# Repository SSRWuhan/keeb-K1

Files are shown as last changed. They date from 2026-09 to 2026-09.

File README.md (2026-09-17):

# keeb-K1
This is my keyboard design for the KEEB program from Hack Club.

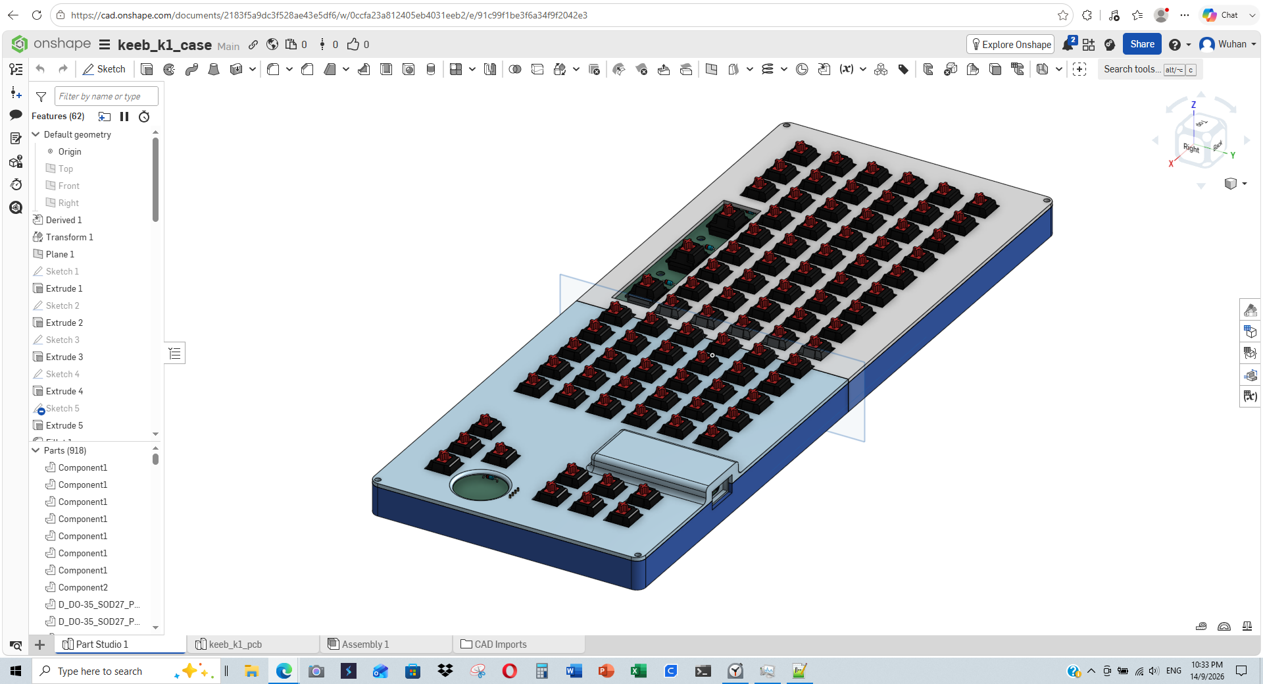
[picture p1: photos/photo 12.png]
Keyboard


This is my very first keyboard! I have designed it so that you can have 6 configurable keys for macros or any other thing, along with joystick for scrolling or for using it as a mouse.

This was my first time making a PCB and writting firmware. Even though I already have experience with CAD, I did learn a few new things while making this.

NOTE: This project is still in active development as I still haven't made it in real life. Also, The firmware is complete, but support for vial is still in the works. Thus, `vial.json` won't work.

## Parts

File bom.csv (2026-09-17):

Product | Description | Quantity | Price(Taka/BDT) | Price(USD) | Sale price(As of when writing this)(Taka/BDT) | Link | Shipping Fee(Taka) | Extra Notes
Rspberry pi pico | The microcontroller | 1 | 1119 | 9.06 | 959 | 【Clearance Markdowns】 Raspberry Pi Pico Board RP2040 TYPE-C / MICRO Dual-Core 264KB ARM Low- Microcomputers High-Performance Cortex-M0+ Processor | Daraz.com.bd | Free(as of writing this)
Mx Cherry linear switches | Switches for the Keyboard | 91 | 3736 | 30.25 | 1532 | 20-100pc Mechanical Keyboard Switches Blue Red Brown Switch Customizable Hot-Swappable 3 Pins Cross Stem for Mechanical Keyboard | Daraz.com.bd | 170 | Due to me needing 91 switches I had to buy the 100 set of switches.
Keycaps set | Base keycap set | 1 | 2366 | 19.16 | 968 | 104pcs ABS Universal Mechanical Keyboard Keycaps Ergonomic Blank Keycaps For Cherry MX Keyboard Replacement OEM Backlit Key Cap | Daraz.com.bd | 170 | This was the only good looking keycap set I could find.
1N4148 Diodes | The diodes for the keyboard matrix. | 91 | 892 | 7.22 | 379 | 100/350pcs Fast Switching Schottky Diode Assorted Kit 1N4001 1N4004 1N4007 1N5408 UF4007 FR207 1N5817 1N5819 1N5822 1N4148 RL207 | Daraz.com.bd | 170 | Due to me only finding a pack of 100 that was the most reliable, I had to buy 100.
Stabilizers | stabilizers for keys bigger than 1u. | 1 set | 979 | 7.93 | 839 | 【Premium Quality】 2X Mechanical Keyboard Steel Plate Balance Shaft Keyboard Accessories Transparent Plate Mounted Stabilizer Wire BRYT | Daraz.com.bd | 170 | This was the only option for stabilizers.
Dual-axis XY Joystick Module | Joystick for the keyboard | 1 | 678 | 5.49 | 281 | For Arduino Dual-axis XY Joystick Module Higher Quality PS2 Joystick Control Lever Sensor KY-023 | Daraz.com.bd | 170
3d Printed Case | The case for the keyboard | 1 | 3161=(284+1012+1014+851) | 25.59 | 3161 | 3D Printing Service in Bangladesh — Instant Price Quote | RoboticsBD | 99 | Even though the case is 1 pcs, but it has been divided into 4 parts so it can printed.
M3 screws | Screws for the case | 4 | 45 | 0.36 | 45 | M3 x 6 8 10 20 25 40mm Flat head Phillips Drive machine Replacement Screw | Daraz.com.bd | 170 | Due to me only finding a pack of 10 I had to buy 10.
Heatset Insert | Heatset inserts for case. | 4 | 924 | 7.48 | 416 | 30/50/100pcs M3 Brass Knurled Heat Set Inserts Threaded Heat Resistant Embedment Nuts for 3D Printing Plastic Injection | Daraz.com.bd | 170 | Due to me only finding this in sets of 30. So, I had to buy 30. The other sets were of 100 or 50 pcs.
1u wide clear keycaps | 1u wide Keys for keys larger than 1u. | 14 | 1384 | 11.21 | 551 | https://www.daraz.com.bd/products/1020pcs-blank-keycaps-abs-frosted-transparent-translucent-1u-r4-keycap-for-mx-switches-mechanical-keyboard-i1572536652-s1263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 | 170 | Due to me only finding this in sets of 10 so I had to buy 20.
PCB | The PCB for the keyboard | 1 | 3729.78 | 30.2 | 20.20(USD)(This is with coupons)(or 2494.75 Taka/BDT) |  | 42.04(USD) or 5192.05 Taka/BDT | There isn't a link for this one since due to there not being a specific optio for it.
TOTAL: |  |  | 19013.78 Taka/BDT | 153.95 USD | 11625.75 taka/BDT or 94.13 USD |  | 6651.05 Taka/BDT or 53.85 USD

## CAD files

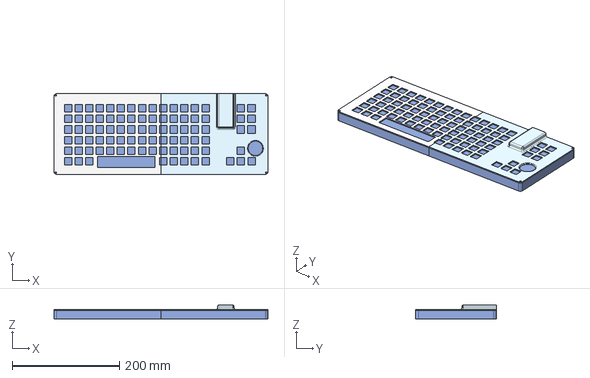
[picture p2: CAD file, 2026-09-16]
case step files/full_case.step
398.6 x 150.5 x 26.0 mm

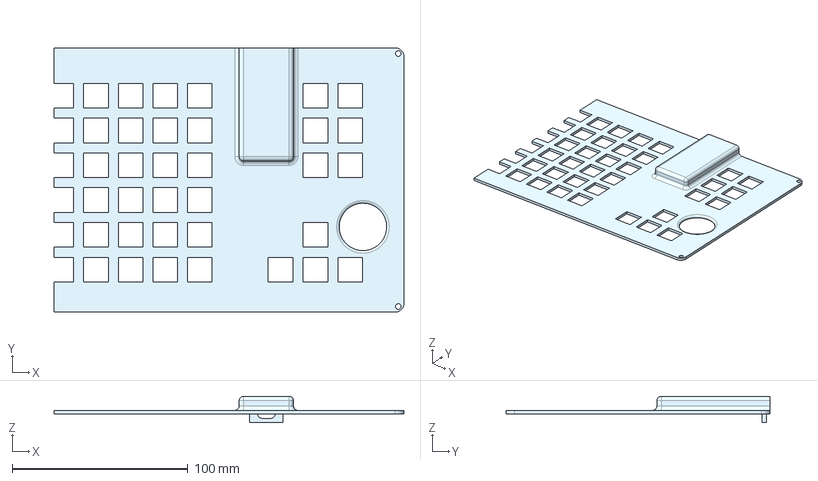
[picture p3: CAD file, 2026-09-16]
case step files/Right top plate.step
199.3 x 150.5 x 15.0 mm

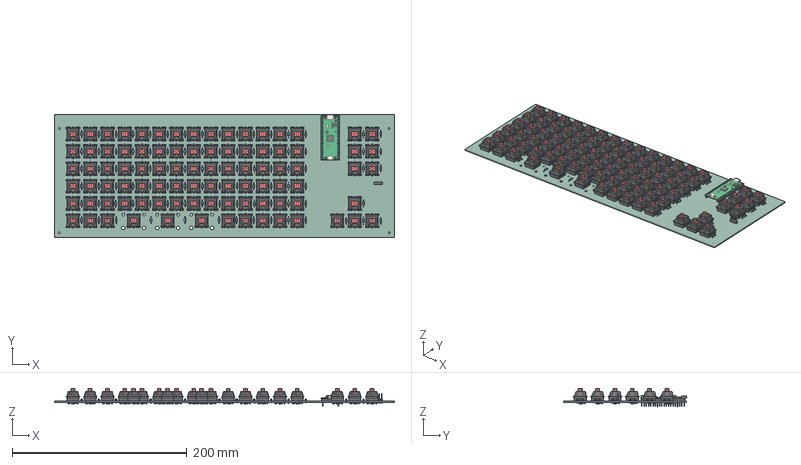
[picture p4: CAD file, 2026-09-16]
pcb/keeb_k1_pcb.step
388.6 x 140.6 x 20.8 mm
D_DO-35_SOD27_P7.62mm_Horizontal x 91
RaspberryPi_Pico_H_Module_KiCad
RaspberryPi_Pico_Header_DIP-40_H2.54mm_KiCad
PinHeader_1x04_P2.54mm_Vertical
keeb_k1_pcb_PCB

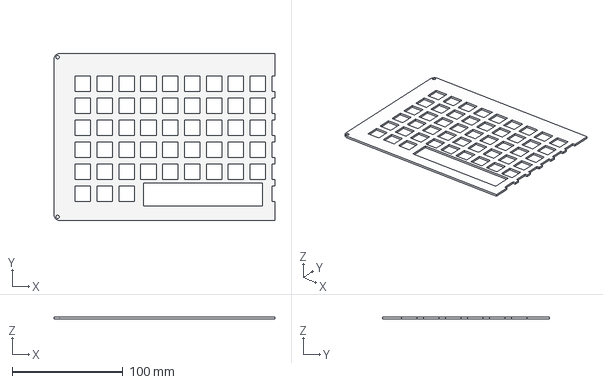
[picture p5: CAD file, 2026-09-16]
case step files/Left top plate.step
199.3 x 150.5 x 2.00 mm

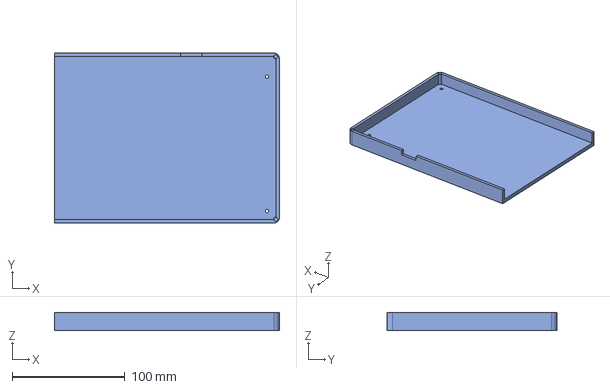
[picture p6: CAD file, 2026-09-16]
case step files/Right bottom case.step
199.3 x 150.5 x 16.0 mm

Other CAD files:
case step files/Left bottom case.step

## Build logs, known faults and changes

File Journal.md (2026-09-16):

## time spent: 19 Minutes, 24 Seconds

This time I made the folder for containing everything for this project. Also, i opened up KiCAD and 
started working on making the keyboard. I didnt do much just placed the raspberry pi pi pico and some switch diode pairs 
in the schematic.

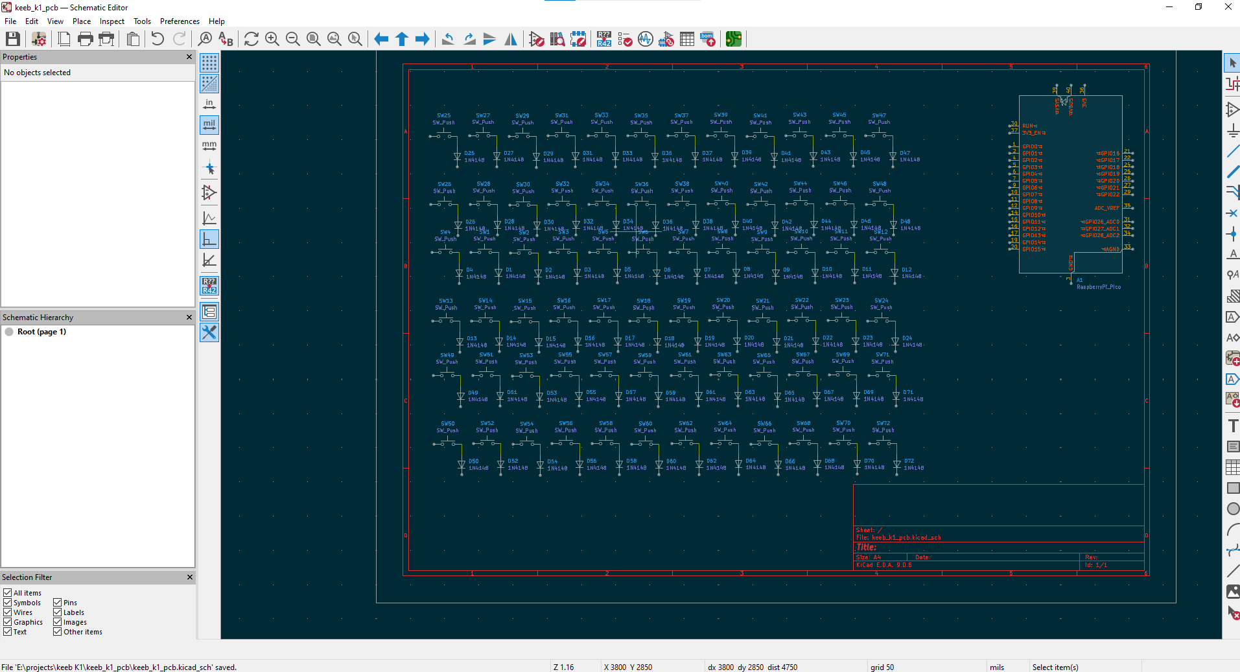
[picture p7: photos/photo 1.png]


## time spent: 55 minutes, 19 seconds

Well, things went a little sideways. When started to wire up all the switches into a grid I realized that
they were not aligned properly. So, I then had to manually correct all of them to get them to finally
connect to the wires. I so far managed to connect all the rows and 7 of the 17 columns connected.
Connecting will be a breeze.

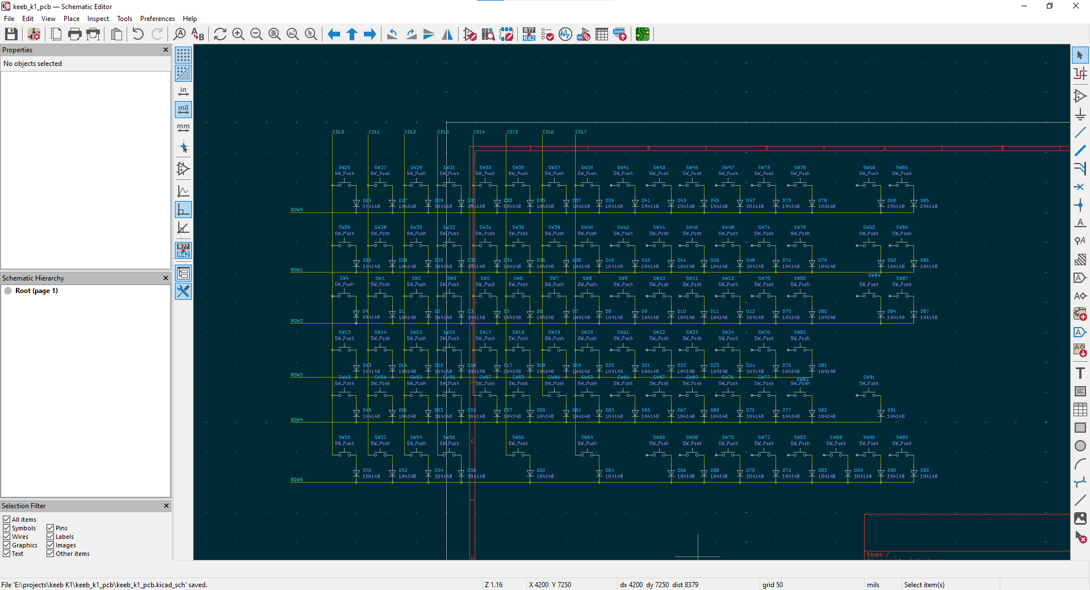
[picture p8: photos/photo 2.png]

## time spent: 1hour, 10 minutes, 47 seconds

I have finally finished wiring up every single switch to the matrix, assign footprints and annotate all the components.
Now, I have started on making the pcb, but as it seems I guess I will have to manually place
all switches in the right order and then satrt placing all the other components next. I was able to organize about 
80% all keys so far. Also, I decided on adding a joystick to my project to simulate a mouse.

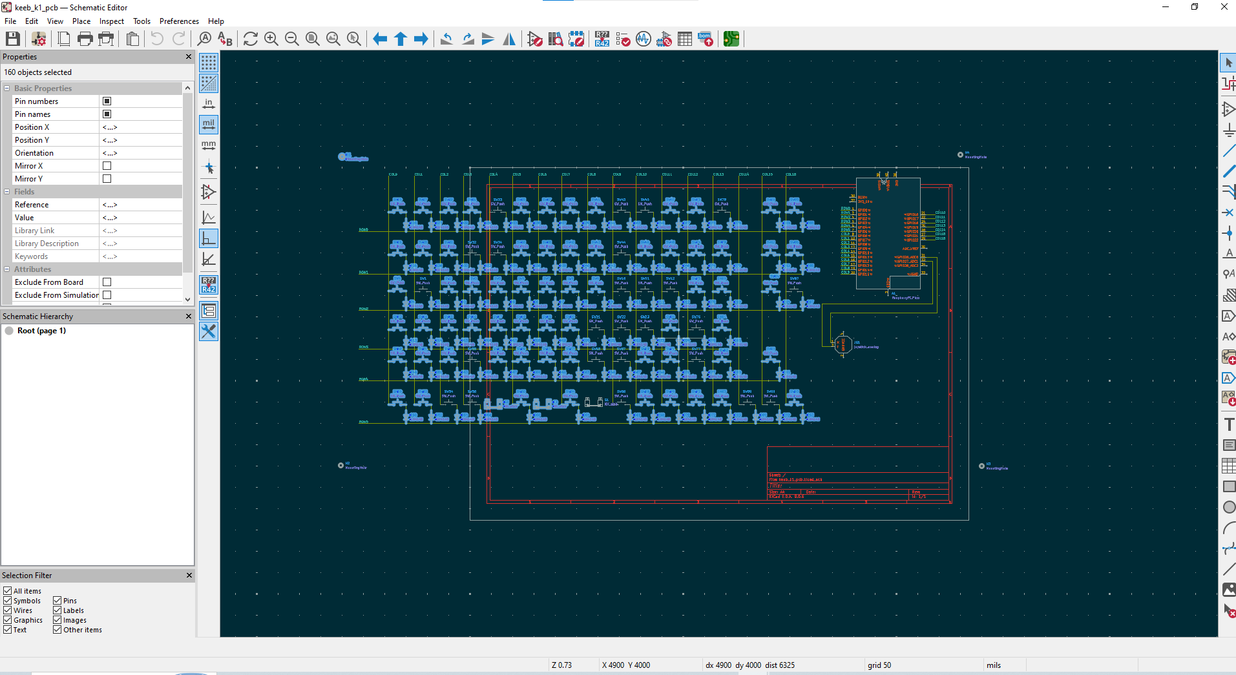
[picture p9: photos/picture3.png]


## time spent: 39 minutes, 54 seconds

I first sorted all the keys in the PCB accordinng to their postions in the matrix. Then I finally began organizing everything 
neatly on the Pcb for the final touches.

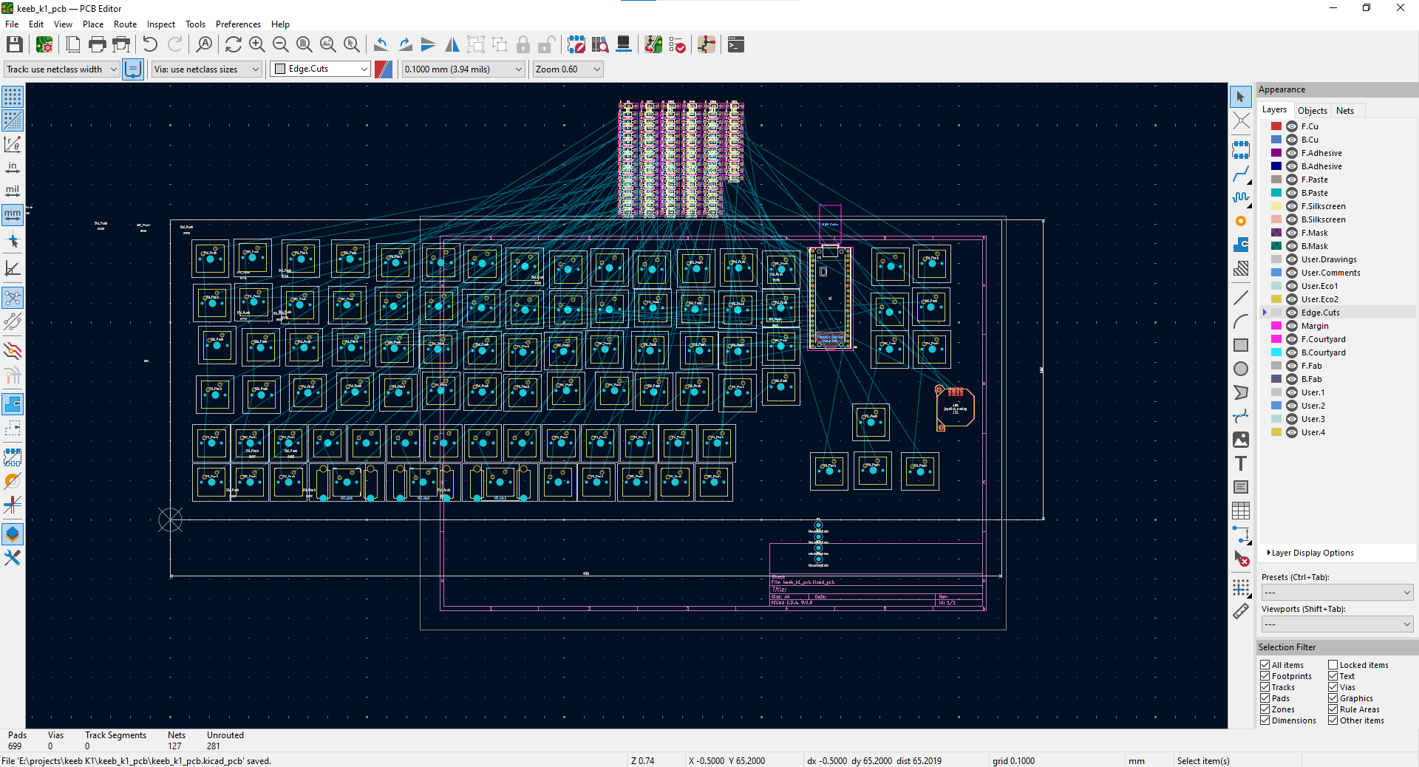
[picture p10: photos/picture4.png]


## time spent: 1hour, 6 minutes, 4 seconds

I finally finished organizing every single switch. I have started to organize the diodes. I
probably have done about 40% of the wor by now. This could have been done if it wasn't for the fact that I had to 
do this manually.

Future me: Turns out there actually was a faster way to do this by using grids and selecting the top of one the
switches. Also I could have just placed them without leaving a little gap between them since the schematic already
accounts for that. 

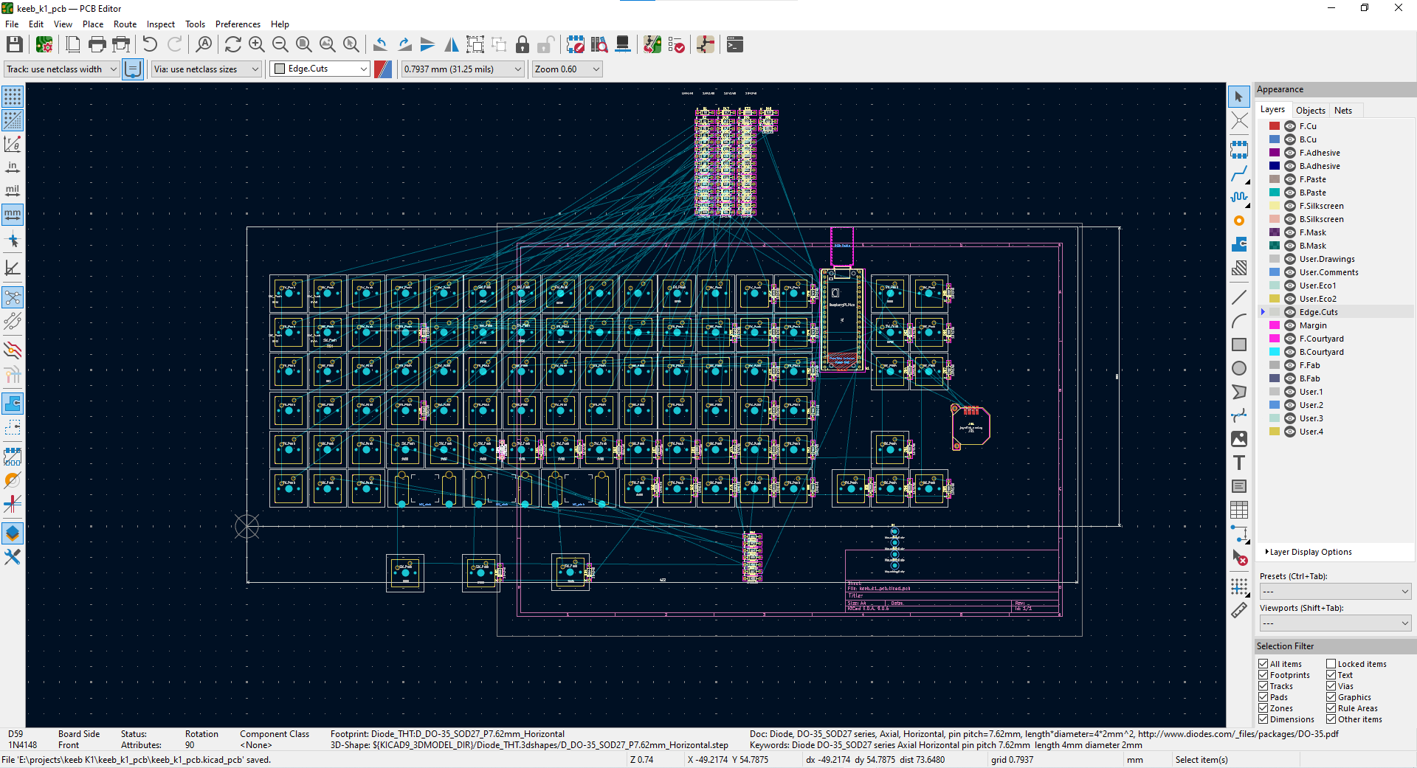
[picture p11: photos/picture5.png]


## time spent: 1hour, 8 min, 7 sec

I finished setting up all the diodes, reaannotated everything and finally started routing the pcb.
It took a while to set up the matrix as I wanted.

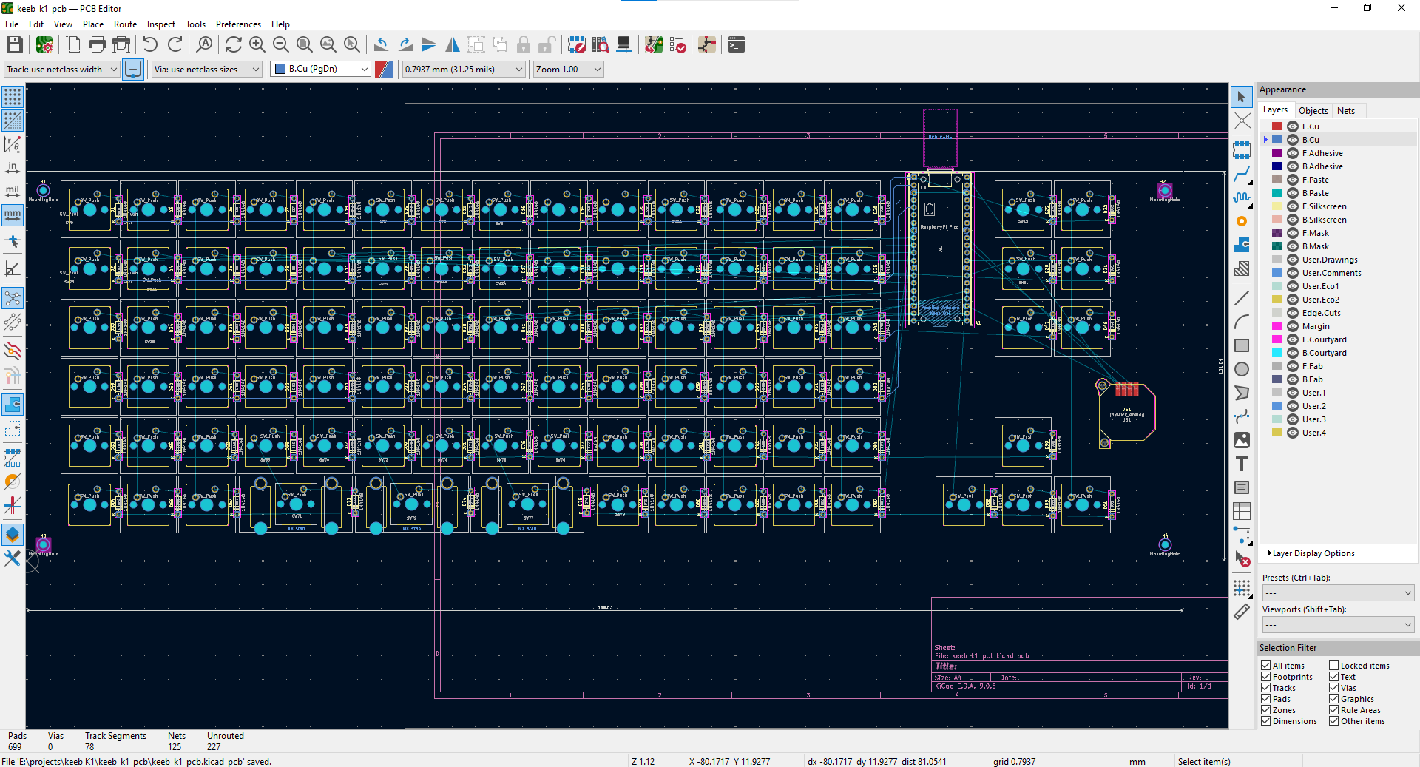
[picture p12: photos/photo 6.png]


## time spent: 56 minutes, 53 seconds

While working on the PCB realized that the joystick footprint I was using was not the right one, so I am now replacing 
it with a 4 pin connector. I also the been re rounting everything for the 3rd time now, since I keep messing up 
the spacing between the keys and the pico. Hopefully from here onwards it will be smooth sailing.

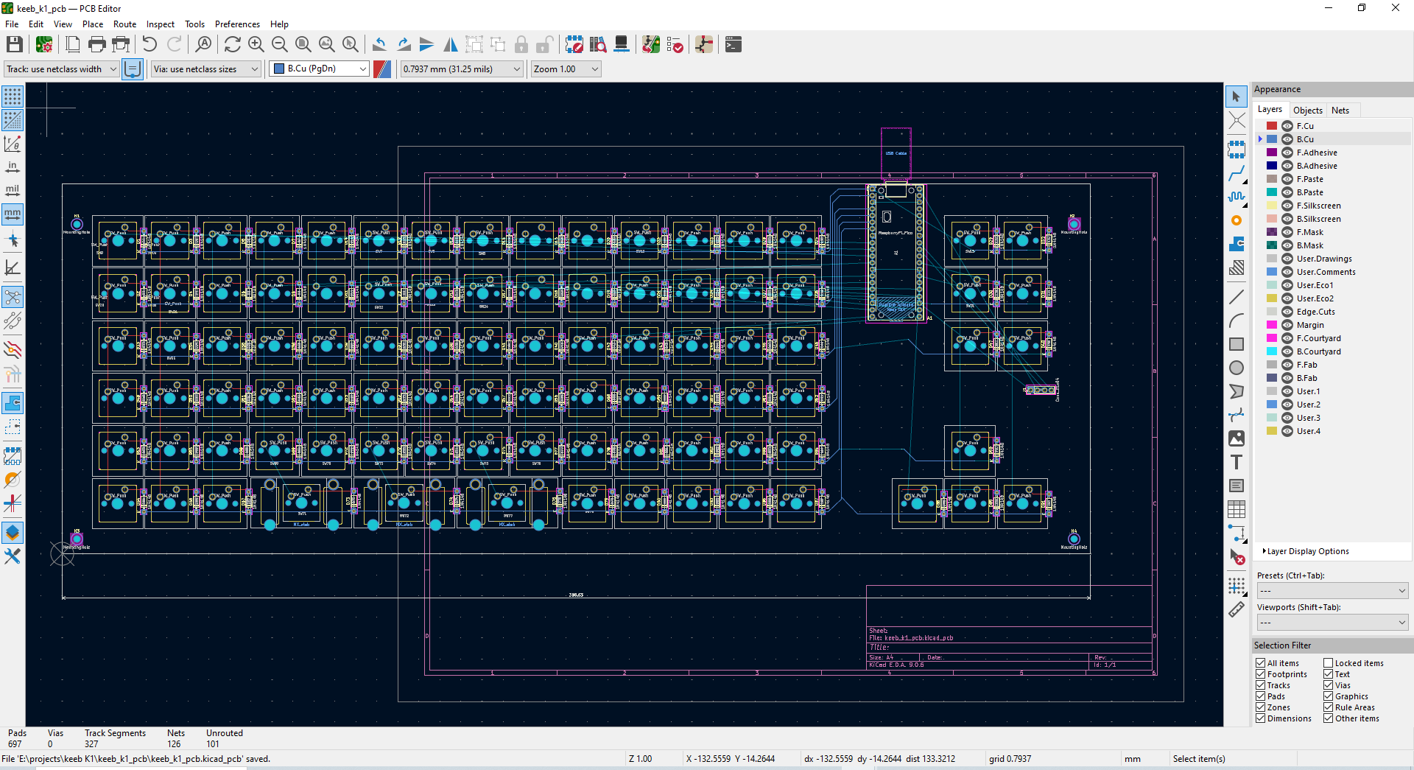
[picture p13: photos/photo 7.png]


## time spent: 1hour

I am finally done making the PCB. But, unfortanately the Cherry MX switches dont have a 3d model attached to 
them, so I am now manually attaching them.

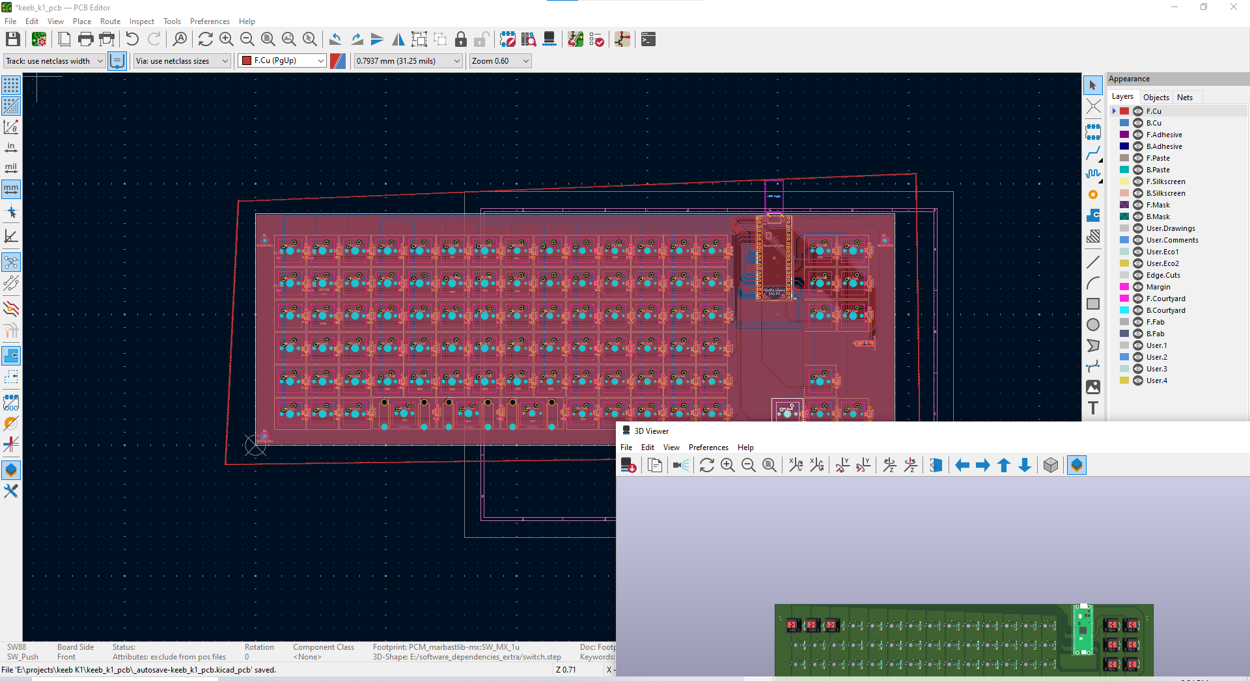
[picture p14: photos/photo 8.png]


## time spent: 50 minutes, 8 seconds

I have completed assigning all the Cherry MX switches with their 3D models and exported stl and gerber files.

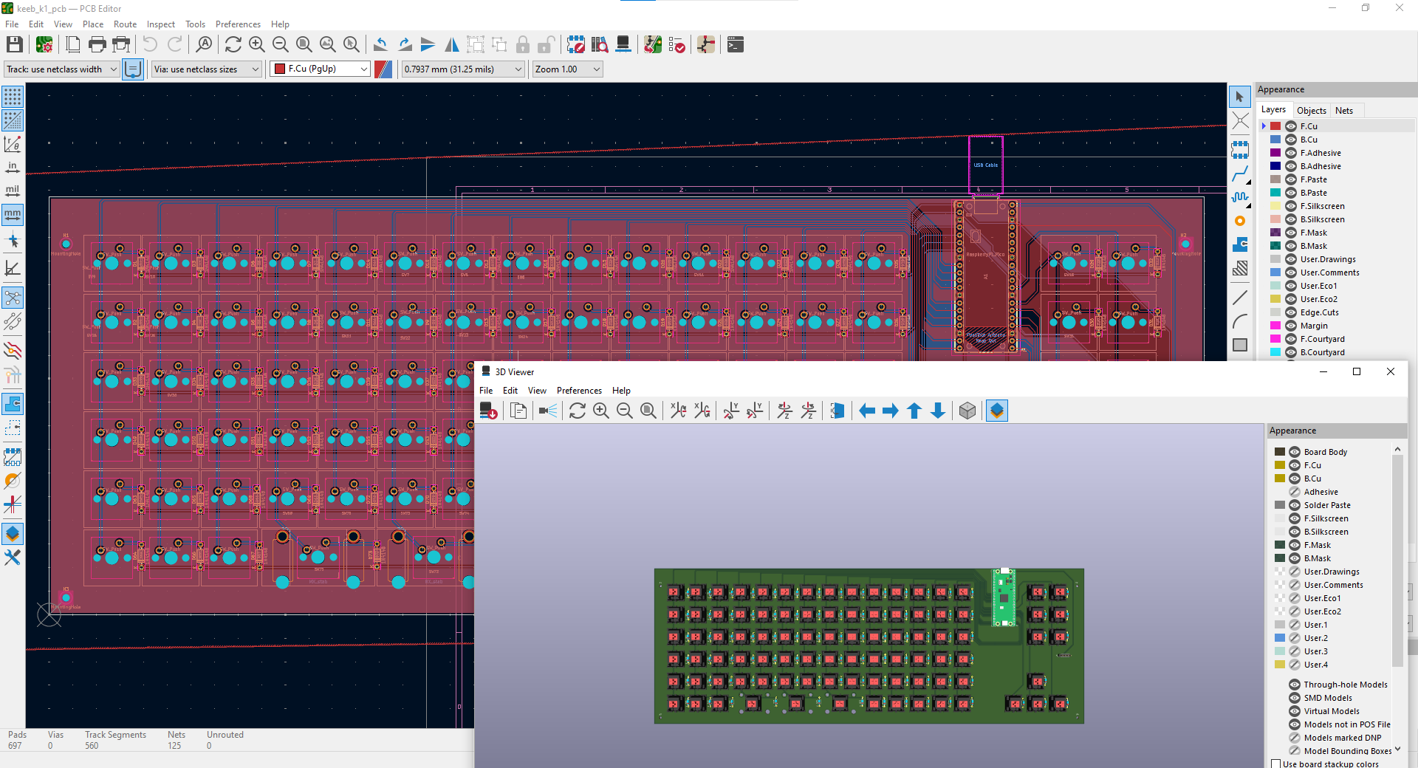
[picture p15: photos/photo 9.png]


## time spent: 2 hours, 11 minutes, 10 Seconds

I have started working on making the case for the keyboard. So far I have exported the PCB model as a 
reference even though it took me a few tries since it was my first time using a another model in CAD directly as a
reference. After that I modeled the bottom, walls and top of the case. I am currently drawing boxes around the keys 
to cut an opening for the keys.

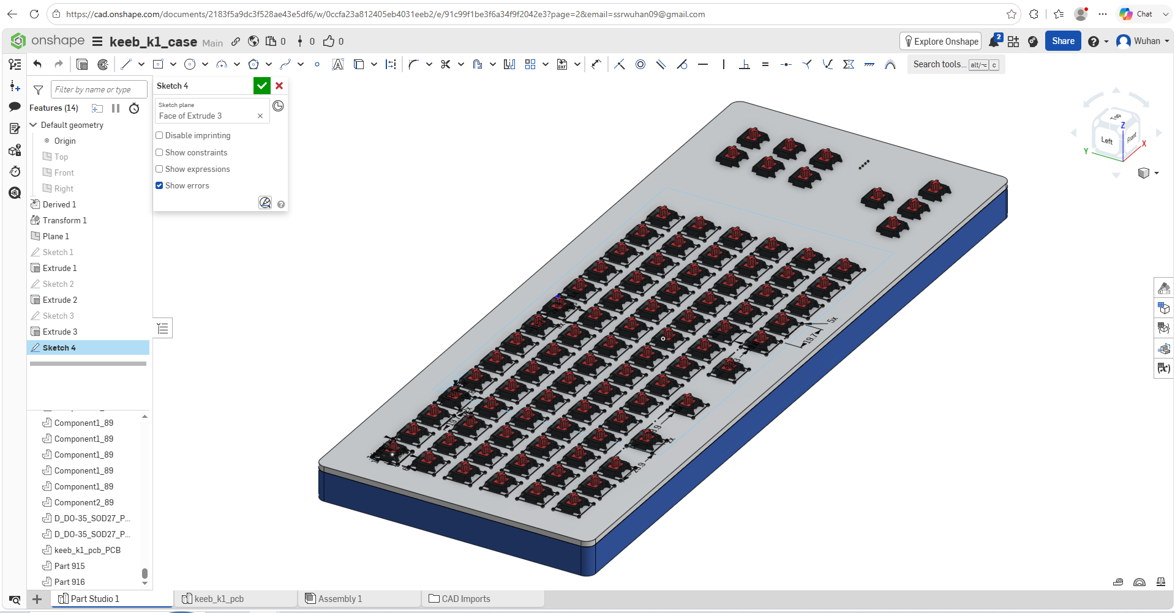
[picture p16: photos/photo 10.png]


## time spent: 1 hour, 22 minute, 4 seconds

I have finished making all the holes for the keys. But I realized after that I need to cut a bigger rectangle for the spacebar
since I need it open so I can place stbailizers fot it. After that I began working on the hole for the joystick. Since, I 
didn't have the 3d model of it on the PCB so, I got the measurements from a joystick model in GrabCAD.
After that Started working on the usb hole, but thankfully I realized that the pico didn't have enough space. I then 
proceaded to make a little compart for it and rounded the edges of it for asthetics. I am now done with cutting the hole and 
now just need to round up the edges.

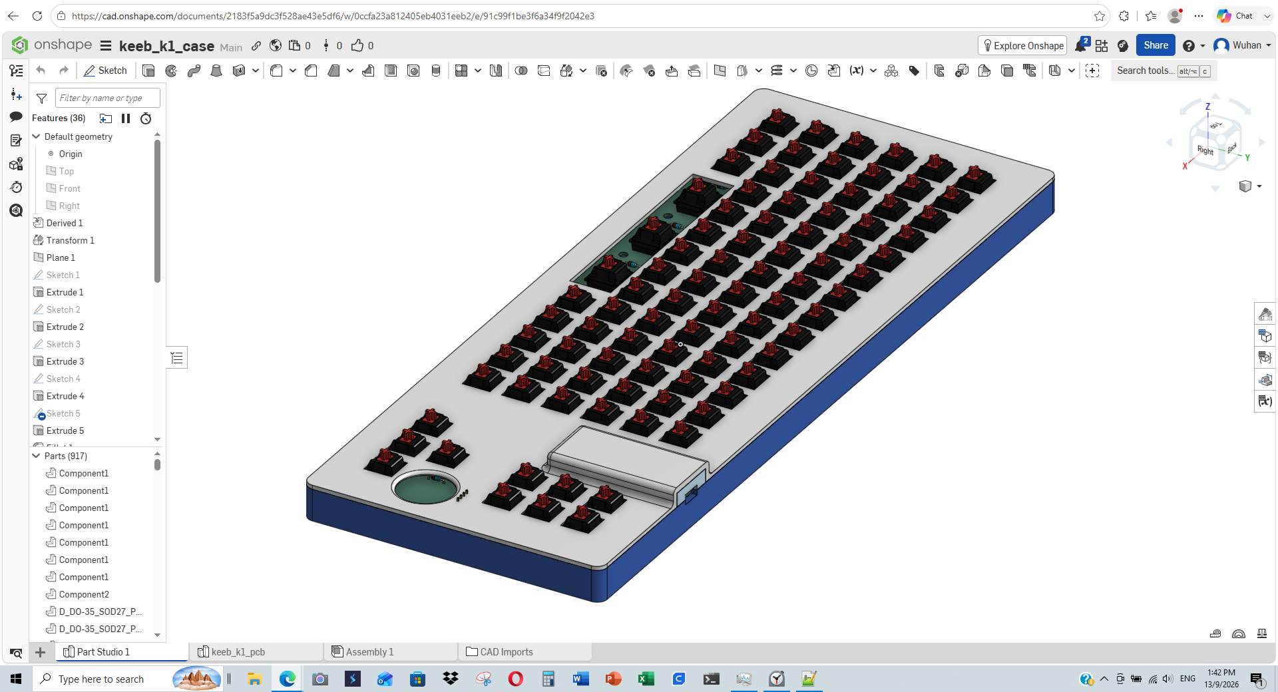
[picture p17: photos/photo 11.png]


## time spent: 1hour, 50 minutes, 29 seconds

Well it longer than expected to make the hole. At first I realized that the outer plastic layer could interfear with the
usb plugging in properly so I first made a big rectangle and then made a ractangular hole for the micro usb. I also rounded up 
the edges with the fillet. After this I began working on making holes for the screws and threads. It was a tight fit. I then split the 
top and bottom of the case into 2 parts. Then I eported everything from Onshape.

PCB

## time spent: 41 minutes, 40 seconds

I wrote a basic firmware for the keyboard with 1 properly made layer. I plan on expanding this later when I have 
physically built the keyboard, along with completing vial.json then.

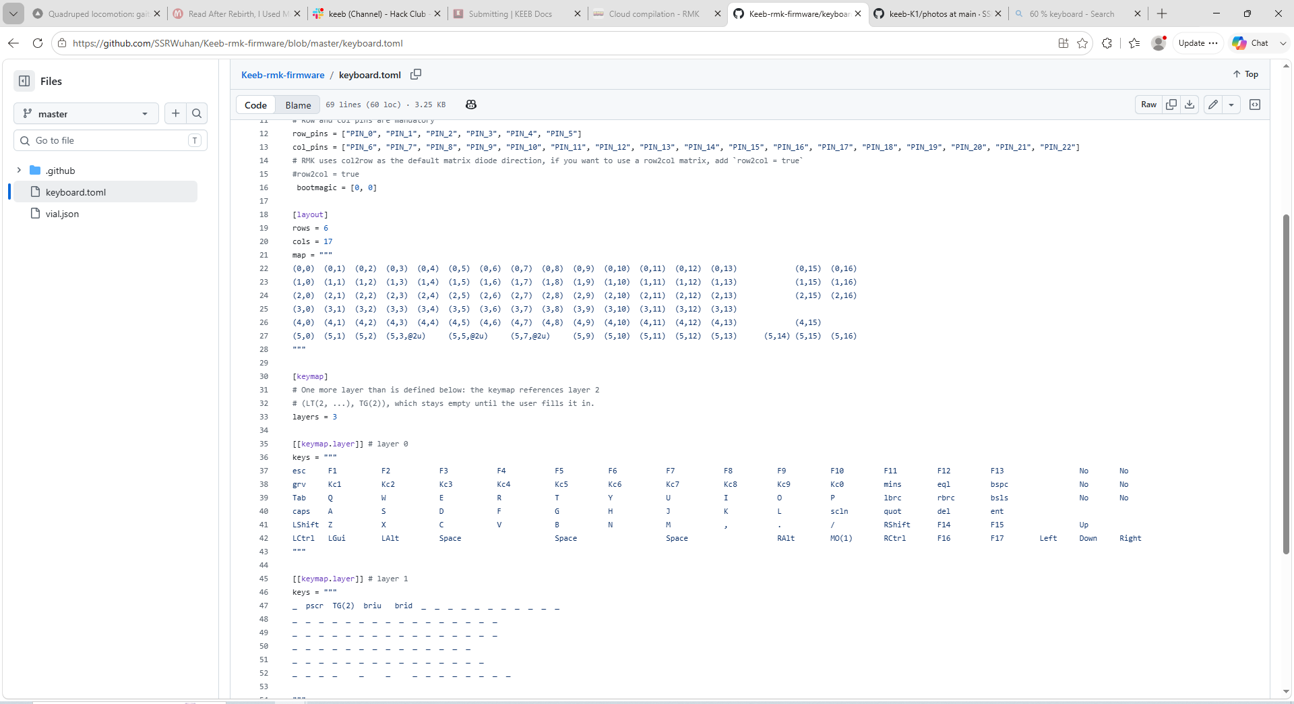
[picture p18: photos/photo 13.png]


# Total time: 14 hours, 11 minutes, 59 seconds

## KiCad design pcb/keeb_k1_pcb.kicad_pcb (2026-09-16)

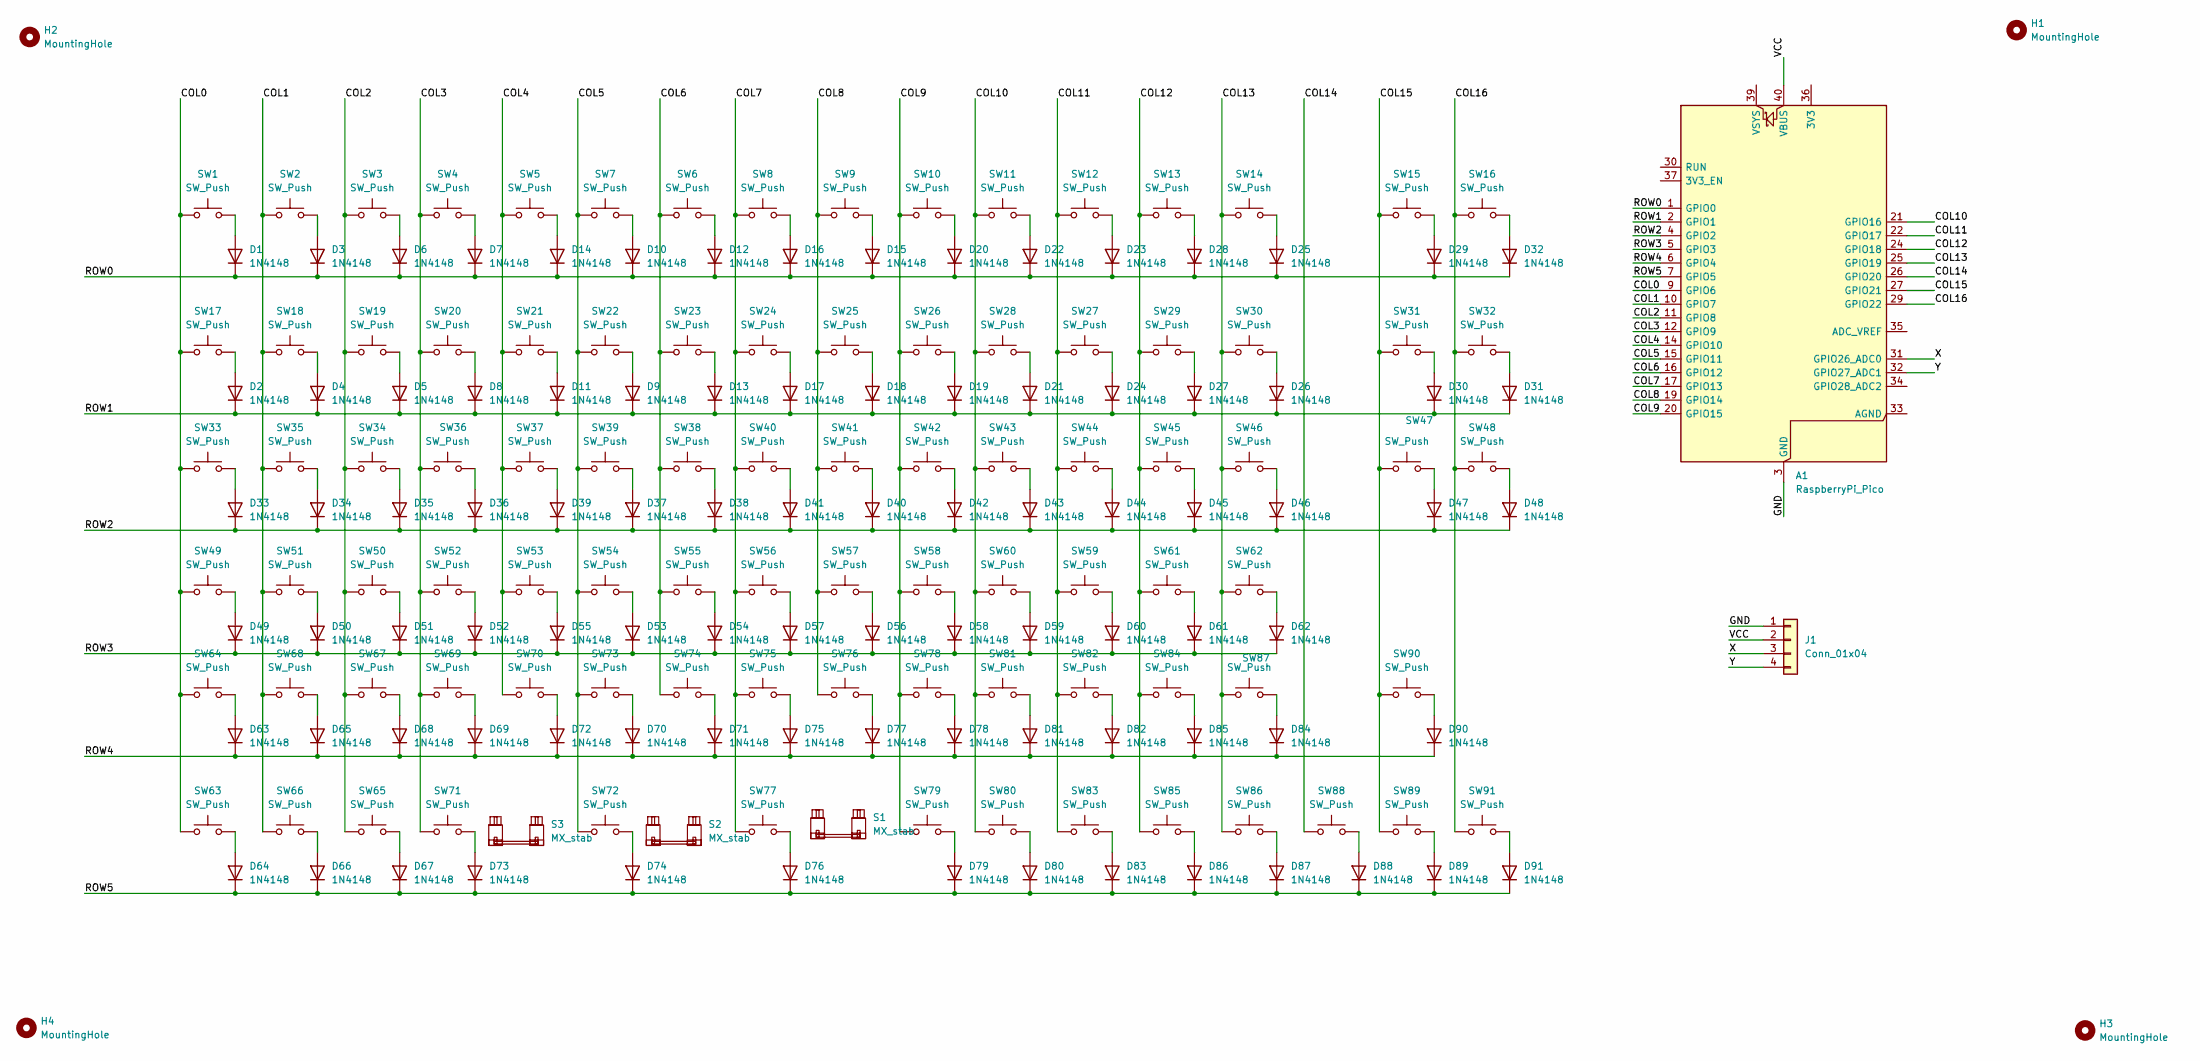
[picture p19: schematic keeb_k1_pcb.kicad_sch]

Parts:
A1: RaspberryPi_Pico; RaspberryPi_Pico_Common_THT
D1, D2, D3, D4, D5, D6, D7, D8, D9, D10, D11, D12, D13, D14, D15, D16, D17, D18, D19, D20, D21, D22, D23, D24, D25, D26, D27, D28, D29, D30, D31, D32, D33, D34, D35, D36, D37, D38, D39, D40, D41, D42, D43, D44, D45, D46, D47, D48, D49, D50, D51, D52, D53, D54, D55, D56, D57, D58, D59, D60, D61, D62, D63, D64, D65, D66, D67, D68, D69, D70, D71, D72, D73, D74, D75, D76, D77, D78, D79, D80, D81, D82, D83, D84, D85, D86, D87, D88, D89, D90, D91: 1N4148; D_DO-35_SOD27_P7.62mm_Horizontal
H1, H2, H3, H4: MountingHole; MountingHole_2.1mm
J1: Conn_01x04; PinHeader_1x04_P2.54mm_Vertical
S1, S2, S3: MX_stab; STAB_MX_P_2u
SW1, SW2, SW3, SW4, SW5, SW6, SW7, SW8, SW9, SW10, SW11, SW12, SW13, SW14, SW15, SW16, SW17, SW18, SW19, SW20, SW21, SW22, SW23, SW24, SW25, SW26, SW27, SW28, SW29, SW30, SW31, SW32, SW33, SW34, SW35, SW36, SW37, SW38, SW39, SW40, SW41, SW42, SW43, SW44, SW45, SW46, SW47, SW48, SW49, SW50, SW51, SW52, SW53, SW54, SW55, SW56, SW57, SW58, SW59, SW60, SW61, SW62, SW63, SW64, SW65, SW66, SW67, SW68, SW69, SW70, SW71, SW72, SW73, SW74, SW75, SW76, SW77, SW78, SW79, SW80, SW81, SW82, SW83, SW84, SW85, SW86, SW87, SW88, SW89, SW90, SW91: SW_Push; SW_MX_1u

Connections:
/COL0: A1.9 (GPIO6), SW1.1, SW17.1, SW33.1, SW49.1, SW63.1, SW64.1
/COL1: A1.10 (GPIO7), SW2.1, SW18.1, SW35.1, SW51.1, SW66.1, SW68.1
/COL2: A1.11 (GPIO8), SW3.1, SW19.1, SW34.1, SW50.1, SW65.1, SW67.1
/COL3: A1.12 (GPIO9), SW4.1, SW20.1, SW36.1, SW52.1, SW69.1, SW71.1
/COL4: A1.14 (GPIO10), SW5.1, SW21.1, SW37.1, SW53.1, SW70.1
/COL5: A1.15 (GPIO11), SW7.1, SW22.1, SW39.1, SW54.1, SW72.1, SW73.1
/COL6: A1.16 (GPIO12), SW6.1, SW23.1, SW38.1, SW55.1, SW74.1
/COL7: A1.17 (GPIO13), SW8.1, SW24.1, SW40.1, SW56.1, SW75.1, SW77.1
/COL8: A1.19 (GPIO14), SW9.1, SW25.1, SW41.1, SW57.1, SW76.1
/COL9: A1.20 (GPIO15), SW10.1, SW26.1, SW42.1, SW58.1, SW78.1, SW79.1
/COL10: A1.21 (GPIO16), SW11.1, SW28.1, SW43.1, SW60.1, SW80.1, SW81.1
/COL11: A1.22 (GPIO17), SW12.1, SW27.1, SW44.1, SW59.1, SW82.1, SW83.1
/COL12: A1.24 (GPIO18), SW13.1, SW29.1, SW45.1, SW61.1, SW84.1, SW85.1
/COL13: A1.25 (GPIO19), SW14.1, SW30.1, SW46.1, SW62.1, SW86.1, SW87.1
/COL14: A1.26 (GPIO20), SW88.1
/COL15: A1.27 (GPIO21), SW15.1, SW31.1, SW47.1, SW89.1, SW90.1
/COL16: A1.29 (GPIO22), SW16.1, SW32.1, SW48.1, SW91.1
/GND: A1.3 (GND), A1.8 (GND), A1.13 (GND), A1.18 (GND), A1.23 (GND), A1.28 (GND), A1.38 (GND), J1.1
/ROW0: A1.1 (GPIO0), D1.1 (K), D3.1 (K), D6.1 (K), D7.1 (K), D10.1 (K), D12.1 (K), D14.1 (K), D15.1 (K), D16.1 (K), D20.1 (K), D22.1 (K), D23.1 (K), D25.1 (K), D28.1 (K), D29.1 (K), D32.1 (K)
/ROW1: A1.2 (GPIO1), D2.1 (K), D4.1 (K), D5.1 (K), D8.1 (K), D9.1 (K), D11.1 (K), D13.1 (K), D17.1 (K), D18.1 (K), D19.1 (K), D21.1 (K), D24.1 (K), D26.1 (K), D27.1 (K), D30.1 (K), D31.1 (K)
/ROW2: A1.4 (GPIO2), D33.1 (K), D34.1 (K), D35.1 (K), D36.1 (K), D37.1 (K), D38.1 (K), D39.1 (K), D40.1 (K), D41.1 (K), D42.1 (K), D43.1 (K), D44.1 (K), D45.1 (K), D46.1 (K), D47.1 (K), D48.1 (K)
/ROW3: A1.5 (GPIO3), D49.1 (K), D50.1 (K), D51.1 (K), D52.1 (K), D53.1 (K), D54.1 (K), D55.1 (K), D56.1 (K), D57.1 (K), D58.1 (K), D59.1 (K), D60.1 (K), D61.1 (K), D62.1 (K)
/ROW4: A1.6 (GPIO4), D63.1 (K), D65.1 (K), D68.1 (K), D69.1 (K), D70.1 (K), D71.1 (K), D72.1 (K), D75.1 (K), D77.1 (K), D78.1 (K), D81.1 (K), D82.1 (K), D84.1 (K), D85.1 (K), D90.1 (K)
/ROW5: A1.7 (GPIO5), D64.1 (K), D66.1 (K), D67.1 (K), D73.1 (K), D74.1 (K), D76.1 (K), D79.1 (K), D80.1 (K), D83.1 (K), D86.1 (K), D87.1 (K), D88.1 (K), D89.1 (K), D91.1 (K)
/VCC: A1.40 (VBUS), J1.2
/X: A1.31 (GPIO26_ADC0), J1.3
/Y: A1.32 (GPIO27_ADC1), J1.4
unnamed: D1.2 (A), SW1.2
unnamed: D2.2 (A), SW17.2
unnamed: D3.2 (A), SW2.2
unnamed: D4.2 (A), SW18.2
unnamed: D5.2 (A), SW19.2
unnamed: D6.2 (A), SW3.2
unnamed: D7.2 (A), SW4.2
unnamed: D8.2 (A), SW20.2
unnamed: D9.2 (A), SW22.2
unnamed: D10.2 (A), SW7.2
unnamed: D11.2 (A), SW21.2
unnamed: D12.2 (A), SW6.2
unnamed: D13.2 (A), SW23.2
unnamed: D14.2 (A), SW5.2
unnamed: D15.2 (A), SW9.2
unnamed: D16.2 (A), SW8.2
unnamed: D17.2 (A), SW24.2
unnamed: D18.2 (A), SW25.2
unnamed: D19.2 (A), SW26.2
unnamed: D20.2 (A), SW10.2
unnamed: D21.2 (A), SW28.2
unnamed: D22.2 (A), SW11.2
unnamed: D23.2 (A), SW12.2
unnamed: D24.2 (A), SW27.2
unnamed: D25.2 (A), SW14.2
unnamed: D26.2 (A), SW30.2
unnamed: D27.2 (A), SW29.2
unnamed: D28.2 (A), SW13.2
unnamed: D29.2 (A), SW15.2
unnamed: D30.2 (A), SW31.2
unnamed: D31.2 (A), SW32.2
unnamed: D32.2 (A), SW16.2
unnamed: D33.2 (A), SW33.2
unnamed: D34.2 (A), SW35.2
unnamed: D35.2 (A), SW34.2
unnamed: D36.2 (A), SW36.2
unnamed: D37.2 (A), SW39.2
unnamed: D38.2 (A), SW38.2
unnamed: D39.2 (A), SW37.2
unnamed: D40.2 (A), SW41.2
unnamed: D41.2 (A), SW40.2
unnamed: D42.2 (A), SW42.2
unnamed: D43.2 (A), SW43.2
unnamed: D44.2 (A), SW44.2
unnamed: D45.2 (A), SW45.2
unnamed: D46.2 (A), SW46.2
unnamed: D47.2 (A), SW47.2
unnamed: D48.2 (A), SW48.2
unnamed: D49.2 (A), SW49.2
unnamed: D50.2 (A), SW51.2
unnamed: D51.2 (A), SW50.2
unnamed: D52.2 (A), SW52.2
unnamed: D53.2 (A), SW54.2
unnamed: D54.2 (A), SW55.2
unnamed: D55.2 (A), SW53.2
unnamed: D56.2 (A), SW57.2
unnamed: D57.2 (A), SW56.2
unnamed: D58.2 (A), SW58.2
unnamed: D59.2 (A), SW60.2
unnamed: D60.2 (A), SW59.2
unnamed: D61.2 (A), SW61.2
unnamed: D62.2 (A), SW62.2
unnamed: D63.2 (A), SW64.2
unnamed: D64.2 (A), SW63.2
unnamed: D65.2 (A), SW68.2
unnamed: D66.2 (A), SW66.2
unnamed: D67.2 (A), SW65.2
unnamed: D68.2 (A), SW67.2
unnamed: D69.2 (A), SW69.2
unnamed: D70.2 (A), SW73.2
unnamed: D71.2 (A), SW74.2
unnamed: D72.2 (A), SW70.2
unnamed: D73.2 (A), SW71.2
unnamed: D74.2 (A), SW72.2
unnamed: D75.2 (A), SW75.2
unnamed: D76.2 (A), SW77.2
unnamed: D77.2 (A), SW76.2
unnamed: D78.2 (A), SW78.2
unnamed: D79.2 (A), SW79.2
unnamed: D80.2 (A), SW80.2
unnamed: D81.2 (A), SW81.2
unnamed: D82.2 (A), SW82.2
unnamed: D83.2 (A), SW83.2
unnamed: D84.2 (A), SW87.2
unnamed: D85.2 (A), SW84.2
unnamed: D86.2 (A), SW85.2
unnamed: D87.2 (A), SW86.2
unnamed: D88.2 (A), SW88.2
unnamed: D89.2 (A), SW89.2
unnamed: D90.2 (A), SW90.2
unnamed: D91.2 (A), SW91.2

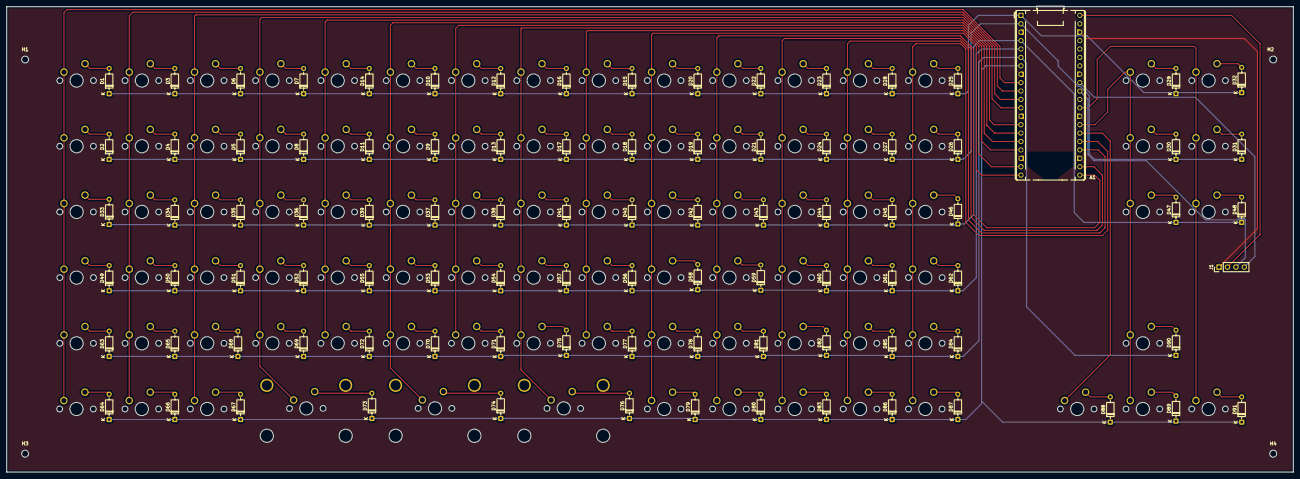
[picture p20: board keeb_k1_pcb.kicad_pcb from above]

Board: 2 copper layers, 388.6 x 140.6 mm, 191 parts (0 on the bottom side), 118 nets.

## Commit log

2026-10-20 Added PCB and schematic pictures
2026-10-21 Added PCB Badge that I found on the Docs for Fabricate
